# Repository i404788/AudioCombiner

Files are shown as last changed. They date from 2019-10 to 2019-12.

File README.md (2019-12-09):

# Audio Combiner/Amp

> Check out the blog post at https://blog.devdroplets.com/stereo-audio-combiner/

This repository contains the KiCAD files for an analog audio combiner (2-stereo signals) with an Class B Amp.
The board is rated up to 18V, but tested on 12V. Excepted power usage at 12V is 3W, though this will depend on your input.
The board is `64.2x34.3x14mm` (smaller than a creditcard in width/height `85.6x54mm`)

The entire board should cost about 13$ (in materials) when produced as one-off; and 7.5$/board when producing in batches of 5; higher quantities should be even cheaper.

# Custom Components/Footprints
This repository contains a custom Lib for KiCAD which includes the TDA1517 (SIP-9) component, which can be reused.
The TDA1517 is a cheap Class B stereo amp, available for 0.17$.

# Screenshots
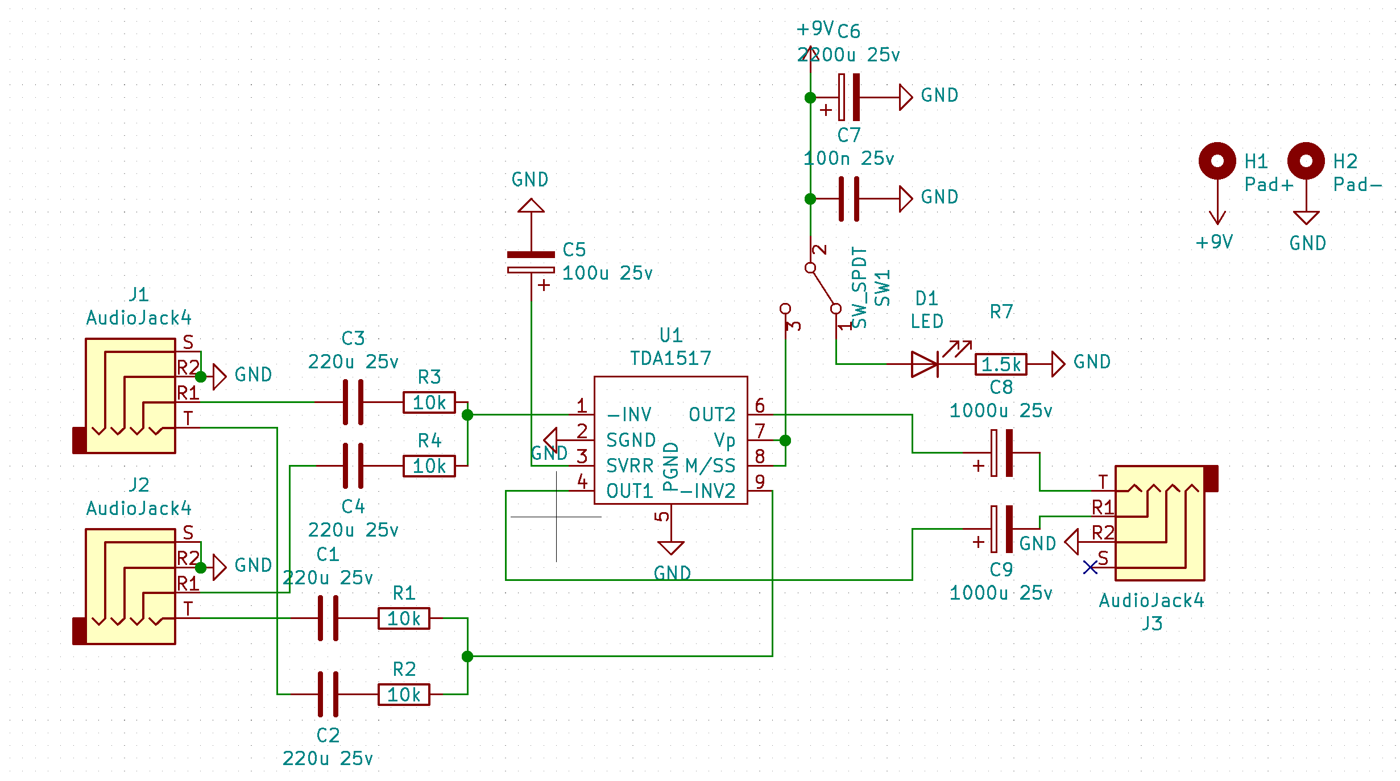
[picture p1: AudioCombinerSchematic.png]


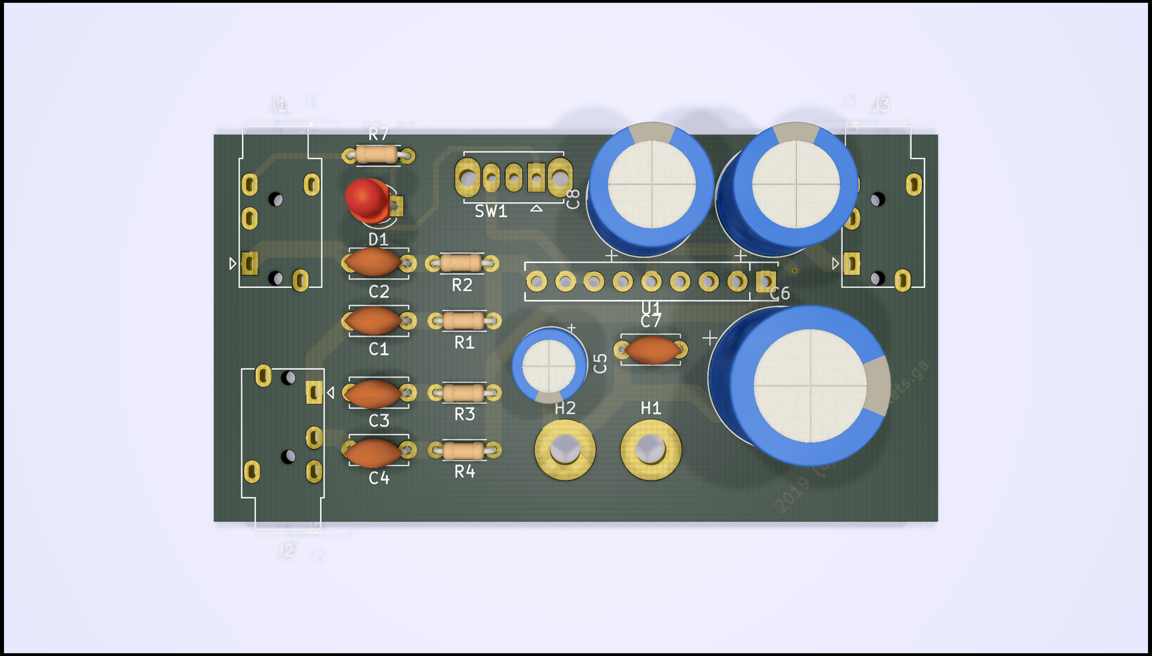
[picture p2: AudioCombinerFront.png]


# License
This hardware is licensed under 
[Creative Commons Attribution 4.0 International License.](https://creativecommons.org/licenses/by/4.0/)



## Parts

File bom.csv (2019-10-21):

Refs | Value | Footprint | Quantity | MFR | MPN | SPR | SPN
SW1 | SW_SPDT | Button_Switch_THT:SW_Slide_1P2T_CK_OS102011MS2Q | 1 | C&K | OS102011MS2QN1C | Mouser | 611-OS102011MS2QN1C
C8;C9 | 1000u 25v | Capacitor_THT:CP_Radial_D10.0mm_P5.00mm | 2 | Panasonic | EEU-FP1E102B | Mouser | 667-EEU-FP1E102B
C6 | 2200u 25v | Capacitor_THT:CP_Radial_D12.5mm_P5.00mm | 1 | Nichicon | UHW1E222MHD1TO | Mouser | 647-UHW1E222MHD1TO
C5 | 100u 25v | Capacitor_THT:CP_Radial_D6.3mm_P2.50mm | 1 | Panasonic | ECA-1EM101B | Mouser | 667-ECA-1EM101B
C7 | 100n 25v | Capacitor_THT:C_Disc_D5.0mm_W2.5mm_P5.00mm | 1 | Vishay / BC Components | K104K15X7RF5TH5 | Mouser | 594-K104K15X7RF5TH5
C3;C4;C2;C1 | 1u 25v | Capacitor_THT:C_Disc_D5.0mm_W2.5mm_P5.00mm | 4 | TDK | FG18X7R1E105KRT00 | Mouser | 810-FG18X7R1E105KRT0
J1;J2;J3 | AudioJack4 | Connector_Audio:Jack_3.5mm_PJ320E_Horizontal | 3 | WQP | PJ320E | AliExpress | https://nl.aliexpress.com/item/1711810776.html
U1 | TDA1517 | KiLib:SOT110-1 | 1 | NXP/PHILIPS | TDA1517 | AliExpress/Si-Tai&SH | https://nl.aliexpress.com/item/32970631051.html
D1 | LED | LED_THT:LED_D3.0mm | 1 | Cree, Inc. | C4SMM-RJF-CS24QBB2 | Mouser | 941-C4SMM-RJF-CS24QBB2
H1 | Pad+ | MountingHole:MountingHole_2.7mm_Pad | 1 | - | - | - | -
H2 | Pad- | MountingHole:MountingHole_2.7mm_Pad | 1 | - | - | - | -
R7 | 1.5k | Resistor_THT:R_Axial_DIN0204_L3.6mm_D1.6mm_P5.08mm_Horizontal | 1 | Vishay / Dale | CCF071K50GKE36 | Mouser | 71-CCF071K50GKE36
R3;R4;R1;R2 | 10k | Resistor_THT:R_Axial_DIN0204_L3.6mm_D1.6mm_P5.08mm_Horizontal | 4 | Yageo | CFR25SJT-52-10K | Mouser | 603-CFR25SJT-52-10K

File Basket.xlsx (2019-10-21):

SHOPPING BASKET
This is not an invoice
23-Sep-19 05:30:00
 | Mouser No | Mfr. No | Manufacturer | Customer No | Description | RoHS | Lifecycle | Order Qty. | Price (EUR) | Ext.: (EUR)
1 | 611-OS102011MS2QN1C | OS102011MS2QN1C | C&K Switches |  | Slide Switches .1A @ 12VDC ON-ON | RoHS Compliant |  | 1 | € 0,441 | € 0,44
2 | 667-EEU-FP1E102 | EEU-FP1E102 | Panasonic |  | Aluminium Electrolytic Capacitors - Radial Leaded 25VDC 1000uF 20% ESR 0.052ohm AECQ200 | RoHS Compliant | New Product | 2 | € 0,999 | € 2,00
3 | 647-UHW1E222MHD1TO | UHW1E222MHD1TO | Nichicon |  | Aluminium Electrolytic Capacitors - Radial Leaded 2200uF 20% 25V High Ripple Current | RoHS Compliant | New Product | 1 | € 1,44 | € 1,44
4 | 594-K104K15X7RF5TH5 | K104K15X7RF5TH5 | Vishay |  | Multilayer Ceramic Capacitors MLCC - Leaded 0.1uF 50volts 10% X7R 5mm LS | RoHS Compliant By Exemption |  | 1 | € 0,234 | € 0,23
5 | 810-FG18X7R1E105KRT0 | FG18X7R1E105KRT00 | TDK |  | Multilayer Ceramic Capacitors MLCC - Leaded RAD 25V 1uF X7R 10% LS:2.5mm | RoHS Compliant |  | 4 | € 0,252 | € 1,01
6 | 71-CCF071K50GKE36 | CCF071K50GKE36 | Vishay |  | Metal Film Resistors - Through Hole 1/4watt 1.5Kohms 2% Rated to 1/2watt | RoHS Compliant |  | 1 | € 0,09 | € 0,09
7 | 603-CFR25SJT-52-10K | CFR25SJT-52-10K | Yageo |  | Carbon Film Resistors - Through Hole 10Kohm 5% 1/4WS Carbon Film | RoHS Compliant | New At Mouser | 4 | € 0,09 | € 0,36
8 | 941-C4SMMRJFCS24QBB2 | C4SMM-RJF-CS24QBB2 | Cree, Inc. |  | Standard LEDs - Through Hole Red Oval | RoHS Compliant | End of Life | 1 | € 0,099 | € 0,10
9 | 667-ECA-1EM101B | ECA-1EM101B | Panasonic |  | Aluminium Electrolytic Capacitors - Radial Leaded Al Lytic Cap 85C Radial M Series | RoHS Compliant |  | 1 | € 0,225 | € 0,23
 |  |  |  |  |  |  |  |  | Merchandise Total: | € 5,90
Prices are reflected at the date and time shown.

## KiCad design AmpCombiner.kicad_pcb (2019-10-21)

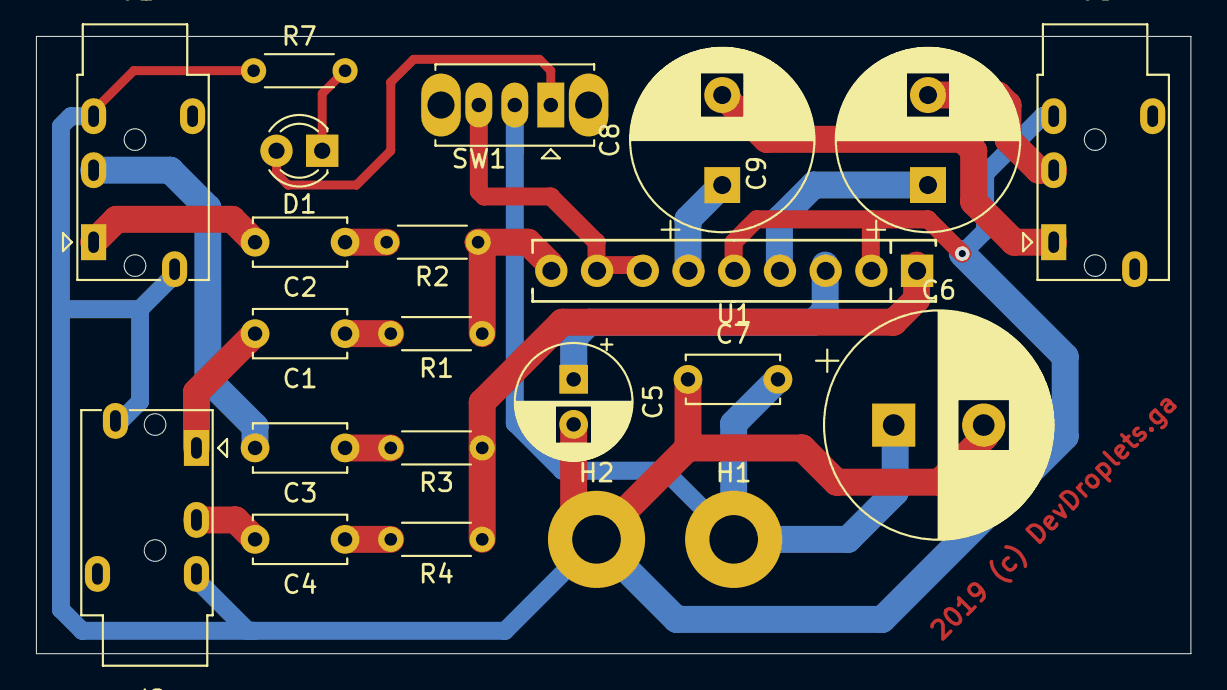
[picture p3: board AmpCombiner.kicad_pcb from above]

Board: 2 copper layers, 64.1 x 34.3 mm, 22 parts (0 on the bottom side), 20 nets.

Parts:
C1, C2, C3, C4: 220u 25v; C_Disc_D5.0mm_W2.5mm_P5.00mm
C5: 100u 25v; CP_Radial_D6.3mm_P2.50mm
C6: 2200u 25v; CP_Radial_D12.5mm_P5.00mm
C7: 100n 25v; C_Disc_D5.0mm_W2.5mm_P5.00mm
C8, C9: 1000u 25v; CP_Radial_D10.0mm_P5.00mm
D1: LED; LED_D3.0mm
H1: Pad+; MountingHole_2.7mm_Pad
H2: Pad-; MountingHole_2.7mm_Pad
J1, J2, J3: AudioJack4; Jack_3.5mm_PJ320E_Horizontal
R1, R2, R3, R4: 10k; R_Axial_DIN0204_L3.6mm_D1.6mm_P5.08mm_Horizontal
R7: 1.5k; R_Axial_DIN0204_L3.6mm_D1.6mm_P5.08mm_Horizontal
SW1: SW_SPDT; SW_Slide_1P2T_CK_OS102011MS2Q
U1: TDA1517; SIP9_Housing

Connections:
+9V: C6.1, C7.2, H1.1, SW1.2
GND: C5.2, C6.2, C7.1, H2.1, J1.R2, J1.S, J2.R2, J2.S, J3.R2, R7.1, U1.2, U1.5
unnamed: C1.1, R1.2
unnamed: C1.2, J2.T
unnamed: C2.1, R2.2
unnamed: C2.2, J1.T
unnamed: C3.1, R3.2
unnamed: C3.2, J1.R1
unnamed: C4.1, R4.2
unnamed: C4.2, J2.R1
unnamed: C5.1, U1.3
unnamed: C8.1, U1.6
unnamed: C8.2, J3.T
unnamed: C9.1, U1.4
unnamed: C9.2, J3.R1
unnamed: D1.1, R7.2
unnamed: D1.2, SW1.1
unnamed: R1.1, R2.1, U1.9
unnamed: R3.1, R4.1, U1.1
unnamed: SW1.3, U1.7, U1.8

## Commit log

2019-10-21 Add board, BOM, README
    [AmpCombiner.kicad_pcb, AmpCombiner.sch, Basket.xlsx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]
2019-10-21 Update docs, standard footprint
    [AmpCombiner.kicad_pcb, AmpCombiner.sch]
